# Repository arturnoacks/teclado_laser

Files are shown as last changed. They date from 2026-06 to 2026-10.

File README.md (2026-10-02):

# Teclado Laser Multi-Instrumental
- Projeto Integrado de Computação II - INF16193/ELE16194
- Artur Noack de Souza, Eduarda Tonini Ferri, Heitor Pinheiro Sousa e Luiz Gabriel Figueiredo Carvalho

O projeto consiste em um teclado multi-instrumental cujo acionamento das teclas ocorre ao interromper um feixe *laser*. De modo geral, o sistema de acionamento pode ser resumido em um conjunto de 24 circuitos emissor comum, que são chaveados de acordo com a resistência de cada LDR (inicialmente saturados pela luz dos *lasers*). Os sinais de saída são recebidos pelo Arduino Mega, que se comunica com o Arduino Uno e o VS1053 para gerar uma saída de áudio via porta P2. Parâmetros diversos como volume e instrumento podem ser visualizados e manipulados por meio de uma interface *web* gerenciada por um ESP32. Adicionalmente, um *encoder* rotativo também pode alterar esses parâmetros.

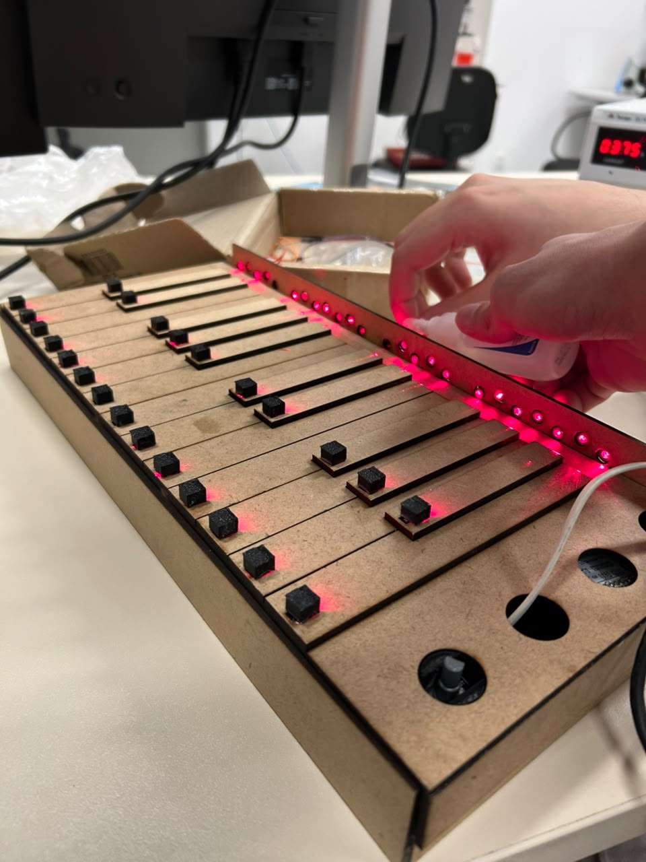
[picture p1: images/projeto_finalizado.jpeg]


Figura 1: Projeto finalizado do teclado laser.

## Descrição do código

O projeto é dividido em duas partes principais:

* **Hardware**: executado nos microcontroladores (Arduino Mega, Arduino Uno e ESP32), responsável pela leitura das teclas, geração do áudio MIDI e comunicação com a interface web.
* **Software**: aplicação responsável pela interface do usuário, permitindo controlar parâmetros do teclado e visualizar, em tempo real, as teclas pressionadas.

### Hardware

#### Arduino Mega

O Arduino Mega é o controlador principal do sistema.

Suas responsabilidades são:

* realizar a leitura das 24 teclas do teclado laser;
* detectar eventos de Note ON e Note OFF;
* converter cada sensor na respectiva nota MIDI;
* aplicar o deslocamento de oitava selecionado;
* enviar comandos MIDI para o Arduino Uno;
* controlar o encoder rotativo para alteração de volume, instrumento e oitava;
* comunicar-se com a ESP32 através da interface Serial2 utilizando mensagens JSON.

#### Arduino Uno + MIDI Shield

O Arduino Uno é responsável exclusivamente pela geração do áudio.

* inicializa o VS1053 em modo Real-Time MIDI;
* recebe os comandos MIDI enviados pelo Arduino Mega através da comunicação serial;
* encaminha esses comandos ao VS1053 via interface SPI;
* reproduz o áudio correspondente ao instrumento e nota selecionados.

#### ESP32

A ESP32 realiza a comunicação entre o hardware e a interface web. Ela conecta-se à rede Wi-Fi, hospeda um servidor WebSocket e faz a troca de mensagens entre o Arduino Mega e a aplicação web. Assim, alterações realizadas na interface são enviadas ao hardware, enquanto os eventos gerados pelo teclado e pelo encoder são transmitidos em tempo real para a interface.

#### Como executar

Carregue cada código na placa correspondente. Antes de fazer upload na ESP32, configure as credenciais da rede Wi-Fi:

```
const char* ssid = "SEU_WIFI";
const char* password = "SUA_SENHA";
```

Após a inicialização, a ESP32 exibirá no monitor serial o seu endereço IP.

### Software

#### Interface web

A interface web permite controlar os principais parâmetros do teclado, como volume, instrumento e oitava, além de exibir, em tempo real, as teclas pressionadas durante a execução. A comunicação com o hardware é realizada por meio de uma conexão WebSocket estabelecida com a ESP32, garantindo a sincronização entre a interface e o instrumento físico.

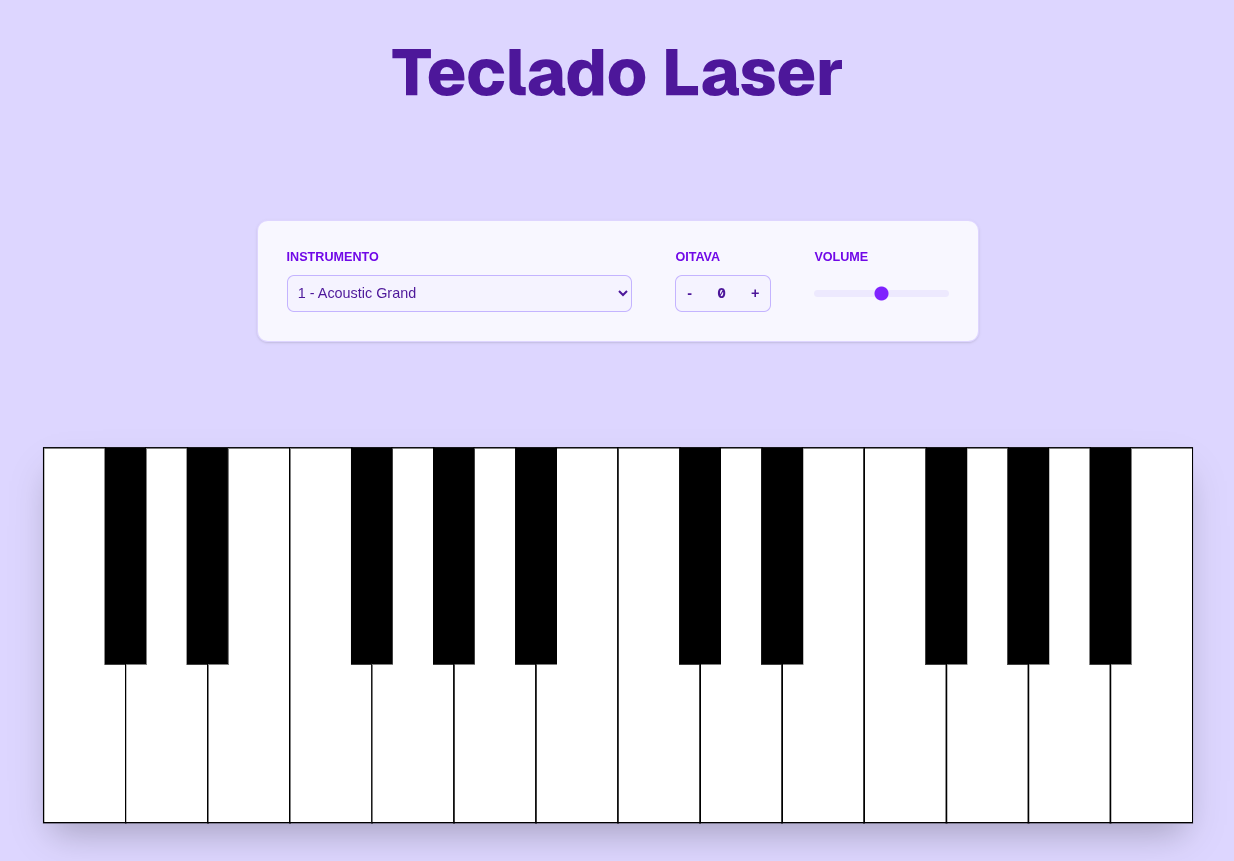
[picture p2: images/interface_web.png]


Figura 2: Tela da interface web.

#### Como executar

Configure o endereço IP da ESP32 utilizado pela conexão WebSocket em app/components/page.tsx:

```
const ESP_IP = "IP_DA_ESP"; 
```

No diretório da aplicação, instale as dependências:

```
npm install
```

Execute o servidor de desenvolvimento:

```
npm run dev
```

Abra http://localhost:3000 no seu navegador para acessar a interface.

## Descrição do material

### Lista de materiais:
- **Micro Controladores:**
	 - Arduino Mega 2560
	 - Arduino Uno
	 - ESP32
	 - Shield Arduino VS1053
 - **Componentes Eletrônicos:**
	 - 24 Módulos Diodo Laser 5V
	 - 24 Resistores 10k, 4.7k
	 - 24 Transistores BC547
	 - 24 LDR 5mm
	 - 1 Encoder Rotativo
 - **Impressões 3D:**
	 - Suportes para carcaça, *encoder* e *lasers*
	 - Proteção para LDRs
- **Outros Materiais:**
	- 4 Placas Fenolite Cobreada
	- 1 Placa Fenolite Perfurada
	- Fios e Jumpers Diversos
	- Carcaça de Madeira

## Modelos 3D (e MDF)
O primeiro modelo feito foi a caixa do piano, que, como seria feita em MDF, foi desenhada no *software* de CAD 2D QCAD. Após confecção desse modelo, ele foi enviado para uma loja de artigos em MDF que produziu grande parte da caixa corretamente, mas houveram algumas adaptações feitas pela loja para facilitar a produção da caixa. Isso fez com que algumas medidas do teclado ao final não sejam condizentes com o modelo do QCAD, mas ainda servem de referência.

O primeiro modelo 3D pensado foram as caixinhas dos LDRs: pequenas caixas pretas vazadas apenas para baixo e para frente, feitas para cobrirem cada LDR virado em direção aos *lasers*, prevenindo interferências de iluminação externa e ao mesmo tempo protegendo o ambiente ao redor do piano de poluição visual dos feixes que atravessassem o LDR. Ao total, foram utilizadas 24 caixinhas.

Conforme o desenvolvimento do projeto, foi percebido que o meio do piano, que é relativamente longo, ficaria curvo e frágil sem sustentação por baixo, ainda mais conforme as teclas fossem pressionadas. Para isso, foram impressos alguns suportes 3D, sendo colados à tampa e possuindo espaços vazados para a passagem de cabos e fios. Na mesma lógica, foi impresso um suporte para o *encoder*, uma vez que ele não poderia ser pressionado sem afundar na caixa caso ele não tivesse uma base firme.

Por fim, a última impressão feita foram os anéis de fixação dos *lasers* na parede posterior do teclado. Eles serviram para maior facilidade para colar os lasers, permitindo uma melhor calibragem do que seria possível caso eles fossem colados diretamente no buraco da parede.

Todos esses modelos constam na pasta "models" do repositório. A maioria dos arquivos estão em FCStd, que é o formato padrão do software FreeCAD utilizado para modelagem 3D das peças.

## Projetos de Placas

O processo de criação das placas foi feita a partir da criação de apenas uma nota, que foi replicada 24 vezes para a completude do piano. Cada uma das notas foi feita à partir de um circuito Emissor Comum, como o da imagem abaixo, de forma que o emissor do transistor fosse conectado direto ao terra, R1 = 4.7k Ohms, Rc = 10k Ohms e R2 fosse um LDR, que possui entre 50 e 100 Ohms quando saturado, ou seja, com o laser apontado. 

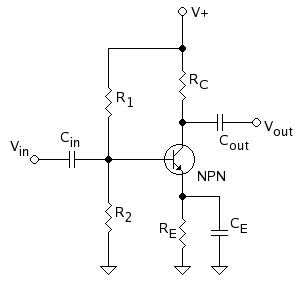
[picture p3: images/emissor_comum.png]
Exemplo de circuito Emissor Comum.


Figura 3: Exemplo de circuito Emissor Comum.

Dessa forma, quando o laser é impedido por um obstáculo, o transistor entra em corte e a saída cai. Quando o obstáculo é retirado, o LDR satura e o transistor volta a passar corrente, e a saída volta a 5V. Essa lógica é invertida em software.

Depois disso, foi utilizado o software KiCad, onde foram feitos 2 projetos, o primeiro sendo a junção de 5 notas e o segundo de 7 notas. 

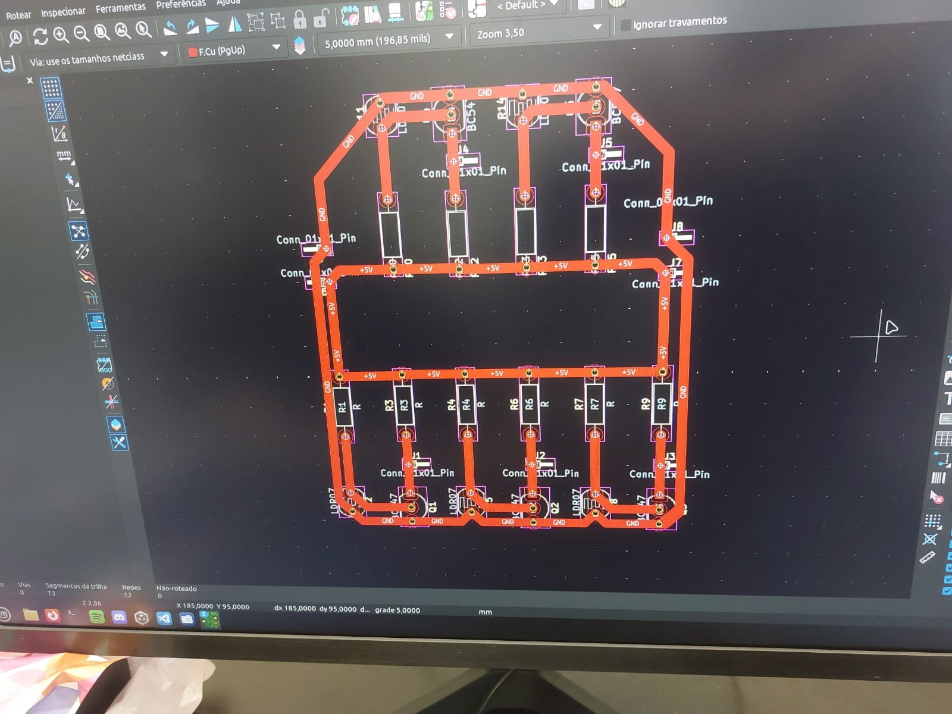
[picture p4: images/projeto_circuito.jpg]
Projeto do circuito de 5 notas no KiCad


Figura 4: Projeto do circuito de 5 notas no KiCad.

Isso foi feito por questão de espaço físico na máquina CnC, que foi utilizada para gravura do circuito na placa. Cada placa foi pintada com uma tinta preta que reage à luz ultra-violeta, de forma que a CnC pudesse disparar um laser forte e secar a tinta no formato do circuito desejado. Depois da gravura, a tinta que não havia sido seca foi retirada com álcool 70%, a placa foi cortada sob medida e por fim imersa em percloreto de ferro, para que o cobre fosse dissolvido.

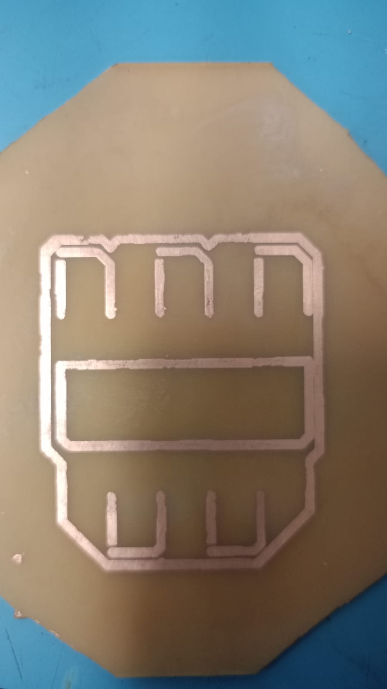
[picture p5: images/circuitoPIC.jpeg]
Placa de circuito impresso de 5 notas


Figura 5: Placa de circuito impresso de 5 notas.

Depois da produção da placa, ela foi limpa e raspada com o lado verde de uma esponja molhada com álcool, e furada manualmente. Então, foram soldados todos os componentes como no projeto desenvolvido. 

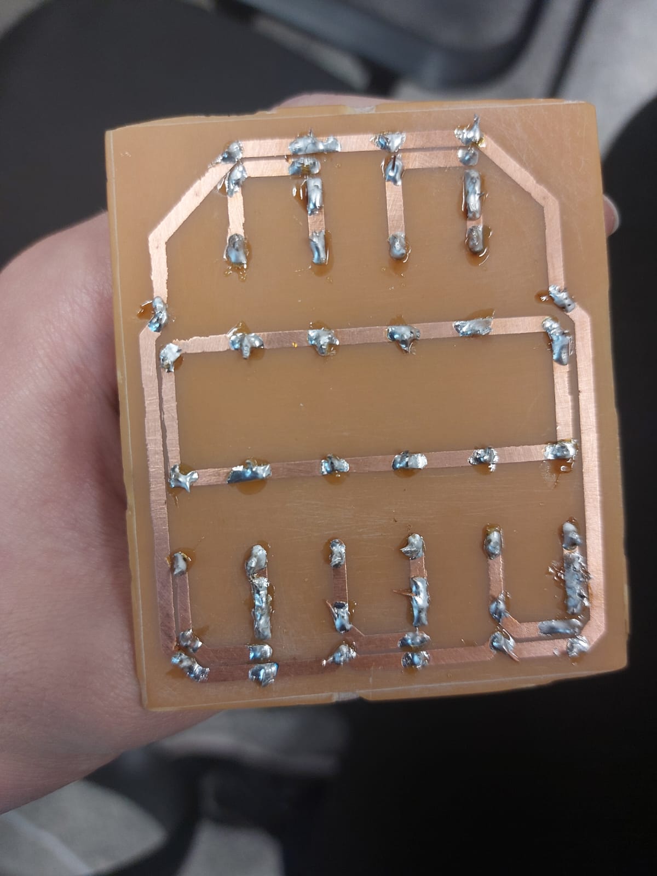
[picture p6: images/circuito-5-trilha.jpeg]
Circuito de 5 notas soldado


Figura 6: Placa de circuito impresso de 5 notas pronta.

As trilhas de 5V e GND foram soldadas com seus equivalentes em cada placa por meio de fios de cobre envernizados, e todos os fios de sinais das notas foram soldados em um barramento comum, que pudesse ser facilmente utilizado para se conectar por jumpers no Arduino Mega utilizado.

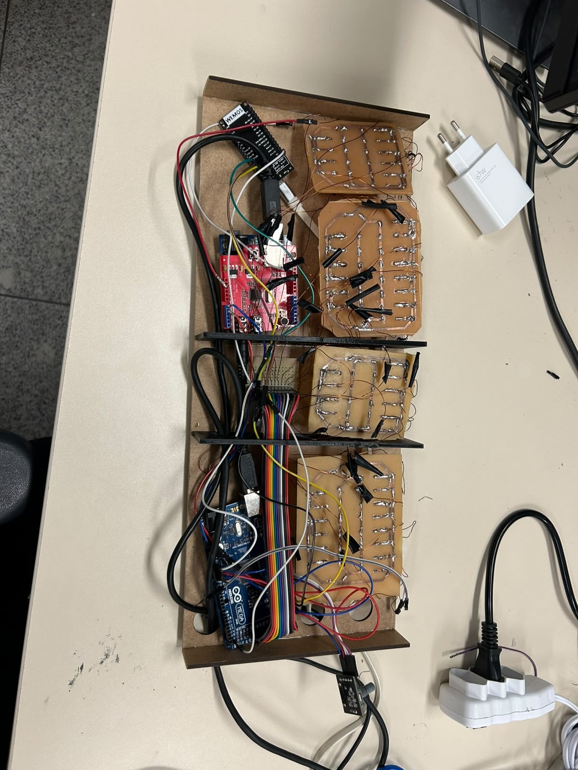
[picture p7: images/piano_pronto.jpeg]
Piano montado com todas as placas soldadas.


Figura 7: Piano montado com todas as placas soldadas.

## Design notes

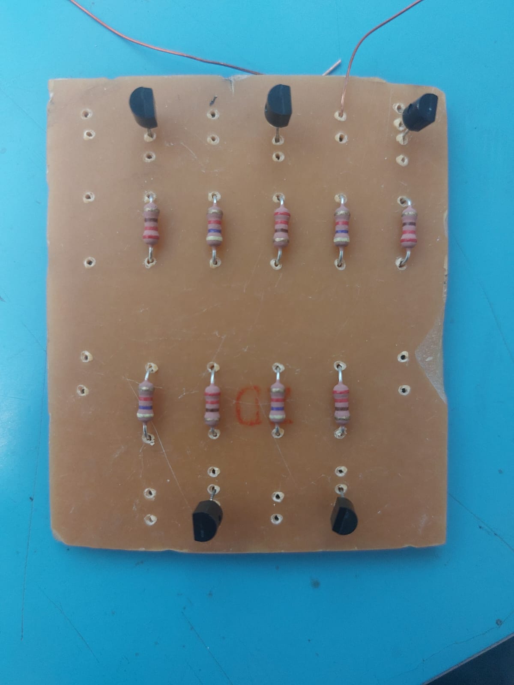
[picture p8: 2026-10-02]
images/circuito-5-frente.jpeg

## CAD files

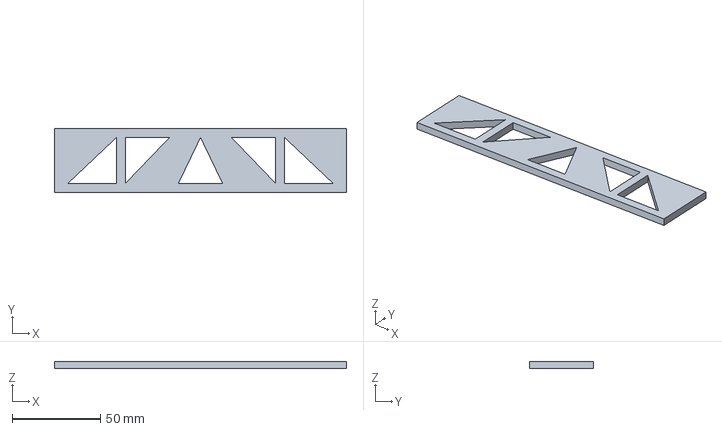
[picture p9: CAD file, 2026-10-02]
models/suportepianolaser.FCStd
165.0 x 36.0 x 4.00 mm

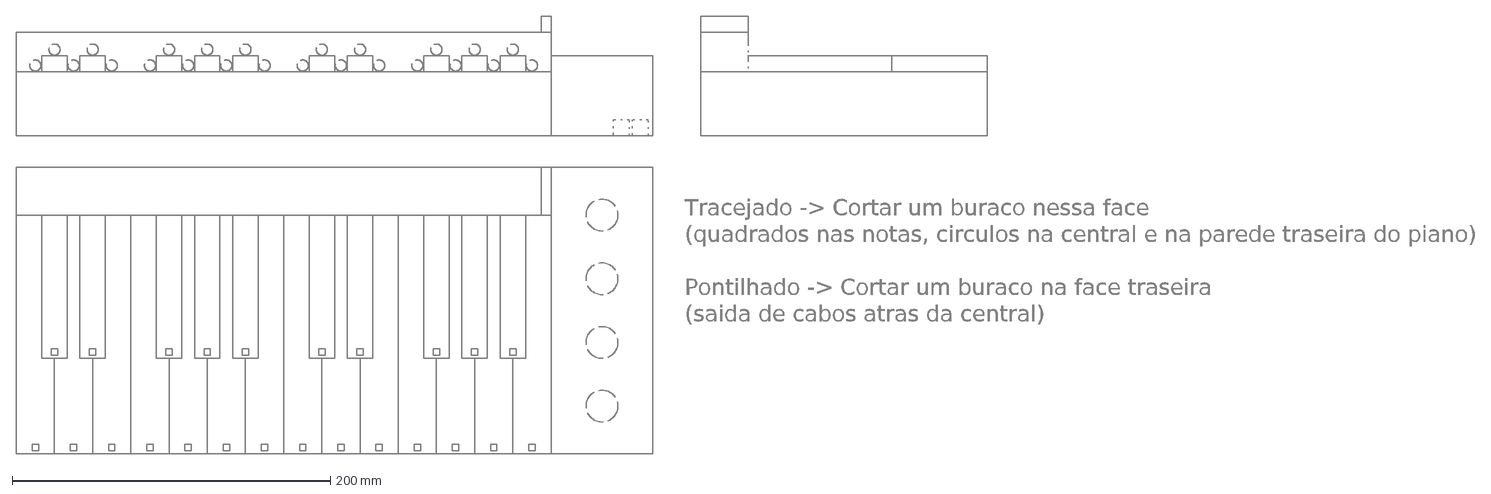
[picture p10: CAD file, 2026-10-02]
models/caixapianolaser.dxf
Tracejado -> Cortar um buraco nessa face (quadrados nas notas, circulos na central e na parede traseira do piano) Pontilhado -> Cortar um buraco na face traseir

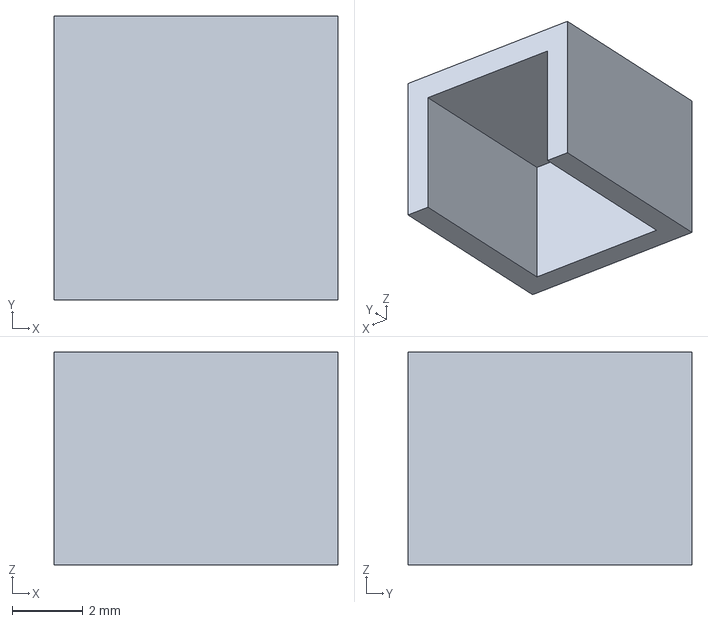
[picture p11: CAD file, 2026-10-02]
models/cabecinhapianolaser.FCStd
8.00 x 8.00 x 6.00 mm

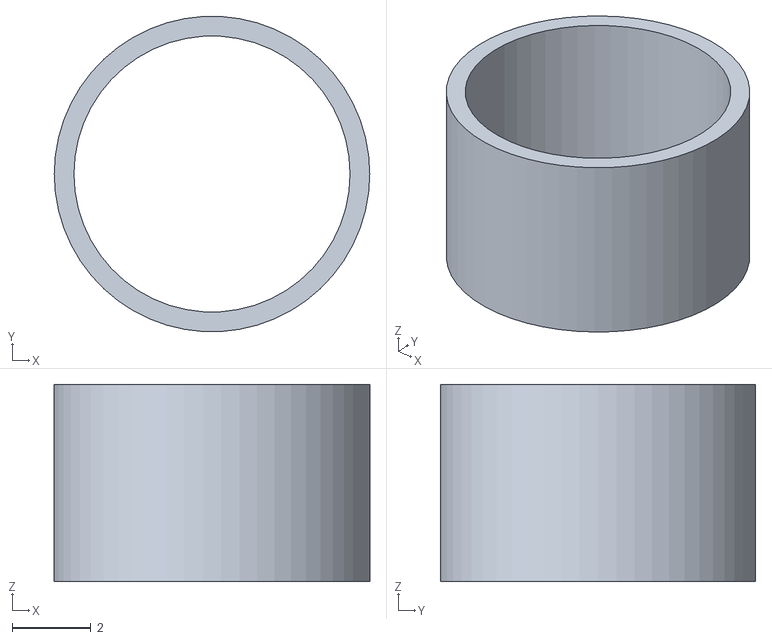
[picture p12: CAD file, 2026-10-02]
models/superluvalaser.stl
8.00 x 7.99 x 5.00

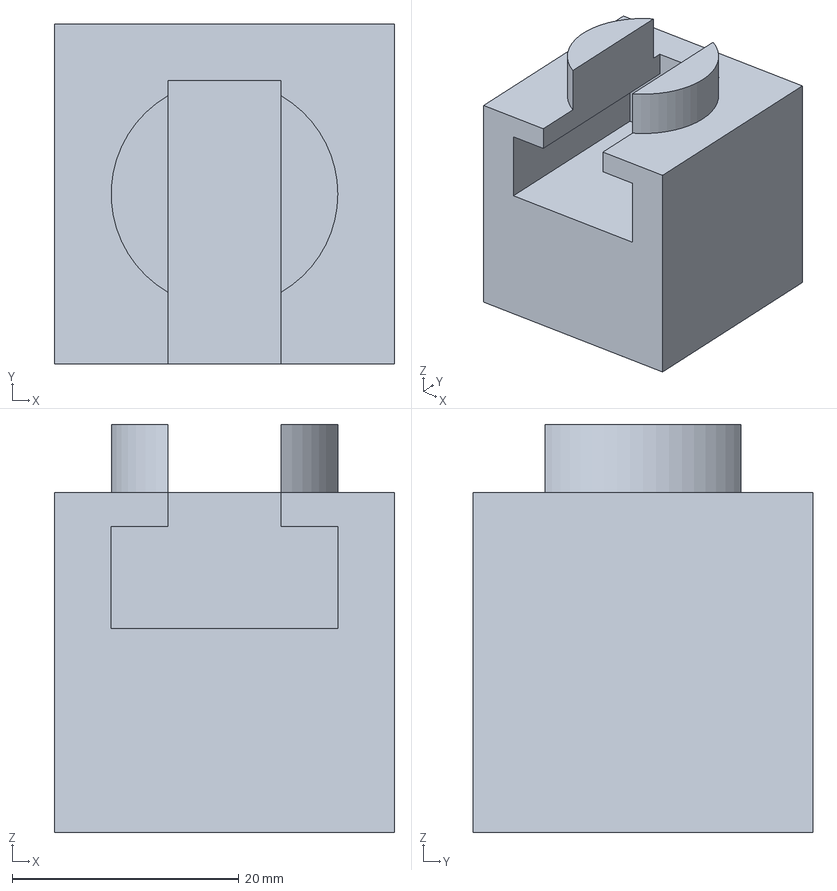
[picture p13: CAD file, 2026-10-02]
models/supencoder.FCStd
30.0 x 30.0 x 36.0 mm

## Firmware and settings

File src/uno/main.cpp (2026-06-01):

#include <Arduino.h>
#include <Wire.h>
#include <SoftwareSerial.h>
/*
// Simple DIY Electronic Music Projects
//    diyelectromusic.wordpress.com
//
//  Arduino MIDI VS1053 Synth
//  https://diyelectromusic.wordpress.com/2020/07/08/arduino-midi-vs1053-synth/
//
      MIT License
      
      Copyright (c) 2020 diyelectromusic (Kevin)
      
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
      THE SOFTWARE IS PROVIDED "AS IS", WITHOUT WARRANTY OF ANY KIND, EXPRESS OR
      IMPLIED, INCLUDING BUT NOT LIMITED TO THE WARRANTIES OF MERCHANTABILITY, FITNESS
      FOR A PARTICULAR PURPOSE AND NONINFRINGEMENT. IN NO EVENT SHALL THE AUTHORS OR
      COPYRIGHT HOLDERS BE LIABLE FOR ANY CLAIM, DAMAGES OR OTHER LIABILITY, WHETHERIN
      AN ACTION OF CONTRACT, TORT OR OTHERWISE, ARISING FROM, OUT OF OR IN CONNECTION
      WITH THE SOFTWARE OR THE USE OR OTHER DEALINGS IN THE SOFTWARE.
*/
/*
  Using principles from the following Arduino tutorials:
    Arduino MIDI Library - https://github.com/FortySevenEffects/arduino_midi_library
    Real-time MIDI Mode for the VS1053 - https://gist.github.com/microtherion/2636608
    Sparkfun Musical Instrument Shield Tutorial - https://www.sparkfun.com/tutorials/302
    VS1053 software patches - http://www.vlsi.fi/en/support/software/vs10xxpatches.html

  This uses a generic VS1053 MP3 Player board that does not
  support booting up into real time MIDI mode and does not
  support the RX/TX serial port MIDI connections.

  If you have a board that supports those, such as the
  SparkFun Musical Instrument Shield linked above, or
  the Adafruit VD1053 breakout board, then things are a
  lot simpler and you can use the basic libraries provided
  with those boards instead.

  This code uses the SPI MIDI mode and a software "patch"
  provided by the VS1053 maufacturers to put the chip into
  real-time MIDI mode.  This is the more complicated technique
  but is pretty much universal on all VS1053 based boards.

  Many thanks to Matthias Neeracher and Nathan Seidle for
  publishing the code that explains how all this works.

*/
#include <SPI.h>
#include <MIDI.h>

// Use binary to say which MIDI channels this should respond to.
// Every "1" here enables that channel. Set all bits for all channels.
// Make sure the bit for channel 10 is set if you want drums.
//
//                               16  12  8   4  1
//                               |   |   |   |  |
uint16_t MIDI_CHANNEL_FILTER = 0b1111111111111111;

// Channel to link to the potentiometer
#define POT_MIDI_CHANNEL 1

// VS1053 Shield pin definitions
#define VS_XCS    6 // Control Chip Select Pin (for accessing SPI Control/Status registers)
#define VS_XDCS   7 // Data Chip Select / BSYNC Pin
#define VS_DREQ   2 // Data Request Pin: Player asks for more data
#define VS_RESET  8 // Reset is active low

// There are three selectable sound banks on the VS1053
// These can be selected using the MIDI command 0xBn 0x00 bank
#define DEFAULT_SOUND_BANK 0x00  // General MIDI 1 sound bank
#define DRUM_SOUND_BANK    0x78  // Drums
#define ISNTR_SOUND_BANK   0x79  // General MIDI 2 sound bank

// List of instruments to send to any configured MIDI channels.
byte preset_instruments[16] = {
/* 01 */  0,
/* 02 */  0,
/* 03 */  0,
/* 04 */  0,
/* 05 */  0,
/* 06 */  0,
/* 07 */  0,
/* 08 */  0,
/* 09 */  0,
/* 10 */  0,  // Channel 10 will be ignored later as that is percussion anyway.
/* 11 */  0,
/* 12 */  0,
/* 13 */  0,
/* 14 */  0,
/* 15 */  0,
/* 16 */  0
};

// This is required to set up the MIDI library.
// The default MIDI setup uses the built-in serial port.
MIDI_CREATE_DEFAULT_INSTANCE();

byte instrument;

byte state = 0;
/***********************************************************************************************
 * 
 * Here is the code to send MIDI data to the VS1053 over the SPI bus.
 *
 * Taken from MP3_Shield_RealtimeMIDI.ino by Matthias Neeracher
 * which was based on Nathan Seidle's Sparkfun Electronics example code for the Sparkfun 
 * MP3 Player and Music Instrument shields and and VS1053 breakout board.
 *
 ***********************************************************************************************
 */
void sendMIDI(byte data) {
  SPI.transfer(0);
  SPI.transfer(data);
}

void talkMIDI(byte cmd, byte data1, byte data2) {
  //
  // Wait for chip to be ready (Unlikely to be an issue with real time MIDI)
  //
  while (!digitalRead(VS_DREQ)) {
  }
  digitalWrite(VS_XDCS, LOW);
  
  sendMIDI(cmd);
  
  //Some commands only have one data byte. All cmds less than 0xBn have 2 data bytes 
  //(sort of: http://253.ccarh.org/handout/midiprotocol/)
  if( (cmd & 0xF0) <= 0xB0 || (cmd & 0xF0) >= 0xE0) {
    sendMIDI(data1);
    sendMIDI(data2);
  } else {
    sendMIDI(data1);
  }

  digitalWrite(VS_XDCS, HIGH);
}


/***********************************************************************************************
 * 
 * Code from here on is the magic required to initialise the VS1053 and 
 * put it into real-time MIDI mode using an SPI-delivered patch.
 * 
 * Here be dragons...
 *
 * Taken from MP3_Shield_RealtimeMIDI.ino by Matthias Neeracher
 * which was based on Nathan Seidle's Sparkfun Electronics example code for the Sparkfun 
 * MP3 Player and Music Instrument shields and and VS1053 breakout board.
 *
 ***********************************************************************************************
 */

void VSLoadUserCode(void);

//Write to VS10xx register
void initialiseVS1053 () {
  // Set up the pins controller the SPI link to the VS1053
  pinMode(VS_DREQ, INPUT);
  pinMode(VS_XCS, OUTPUT);
  pinMode(VS_XDCS, OUTPUT);
  digitalWrite(VS_XCS, HIGH);  //Deselect Control
  digitalWrite(VS_XDCS, HIGH); //Deselect Data
  pinMode(VS_RESET, OUTPUT);

  //Setup SPI for VS1053
  pinMode(10, OUTPUT); // Pin 10 must be set as an output for the SPI communication to work
  SPI.begin();
  SPI.setBitOrder(MSBFIRST);
  SPI.setDataMode(SPI_MODE0);
  
  //From page 12 of datasheet, max SCI reads are CLKI/7. Input clock is 12.288MHz. 
  //Internal clock multiplier is 1.0x after power up. 
  //Therefore, max SPI speed is 1.75MHz. We will use 1MHz to be safe.
  SPI.setClockDivider(SPI_CLOCK_DIV16); //Set SPI bus speed to 1MHz (16MHz / 16 = 1MHz)
  SPI.transfer(0xFF); //Throw a dummy byte at the bus
  
  delayMicroseconds(1);
  digitalWrite(VS_RESET, HIGH); //Bring up VS1053
  
  // Enable real-time MIDI mode
  VSLoadUserCode();
}
//SCI: Data transfers are always 16bit. When a new SCI operation comes in 
//DREQ goes low. We then have to wait for DREQ to go high again.
//XCS should be low for the full duration of operation.
void VSWriteRegister(unsigned char addressbyte, unsigned char highbyte, unsigned char lowbyte){
  while(!digitalRead(VS_DREQ)) ; //Wait for DREQ to go high indicating IC is available
  digitalWrite(VS_XCS, LOW); //Select control
  
  //SCI consists of instruction byte, address byte, and 16-bit data word.
  SPI.transfer(0x02); //Write instruction
  SPI.transfer(addressbyte);
  SPI.transfer(highbyte);
  SPI.transfer(lowbyte);
  while(!digitalRead(VS_DREQ)) ; //Wait for DREQ to go high indicating command is complete
  digitalWrite(VS_XCS, HIGH); //Deselect Control
}

//
// Plugin to put VS10XX into realtime MIDI mode
// Originally from http://www.vlsi.fi/fileadmin/software/VS10XX/vs1053b-rtmidistart.zip
// Permission to reproduce here granted by VLSI solution.
//
const unsigned short sVS1053b_Realtime_MIDI_Plugin[28] = { /* Compressed plugin */
  0x0007, 0x0001, 0x8050, 0x0006, 0x0014, 0x0030, 0x0715, 0xb080, /*    0 */
  0x3400, 0x0007, 0x9255, 0x3d00, 0x0024, 0x0030, 0x0295, 0x6890, /*    8 */
  0x3400, 0x0030, 0x0495, 0x3d00, 0x0024, 0x2908, 0x4d40, 0x0030, /*   10 */
  0x0200, 0x000a, 0x0001, 0x0050,
};

void VSLoadUserCode(void) {
  int i = 0;

  while (i<sizeof(sVS1053b_Realtime_MIDI_Plugin)/sizeof(sVS1053b_Realtime_MIDI_Plugin[0])) {
    unsigned short addr, n, val;
    addr = sVS1053b_Realtime_MIDI_Plugin[i++];
    n = sVS1053b_Realtime_MIDI_Plugin[i++];
    while (n--) {
      val = sVS1053b_Realtime_MIDI_Plugin[i++];
      VSWriteRegister(addr, val >> 8, val & 0xFF);
    }
  }
}

SoftwareSerial SerialMEGA(A0, A1);

void setup() {
      
  // put your setup code here, to run once:
  initialiseVS1053();
  
  // This listens to all MIDI channels
  // They will be filtered out later...
  MIDI.begin(MIDI_CHANNEL_OMNI);

  SerialMEGA.begin(9600);

  Serial.begin(9600);
  pinMode(A2, INPUT);
  

  delay(1000);

  // A test "output" to see if the VS053 is working ok
#ifdef POT_MIDI_CHANNEL
  for (byte i=60; i<73; i++) {
    talkMIDI (0x90|(POT_MIDI_CHANNEL-1), i, 127);
    delay (100);
    talkMIDI (0x80|(POT_MIDI_CHANNEL-1), i, 0);
    delay (200);
  }
  for (byte i=40; i<50; i++) {
    talkMIDI (0x99, i, 127);
    delay (100);
    talkMIDI (0x89, i, 0);
    delay (200);    
  }
#endif

  // Configure the instruments for all required MIDI channels.
  // Even though MIDI channels are 1 to 16, all the code here
  // is working on 0 to 15 (bitshifts, index into array, MIDI command).
  for (byte ch=0; ch<16; ch++) {
    if (ch != 9) { // Ignore channel 10 (drums)
      uint16_t ch_filter = 1<<ch;
      if (MIDI_CHANNEL_FILTER & ch_filter) {
        talkMIDI(0xC0|ch, preset_instruments[ch], 0);
      }
    }
  }
  // For some reason, the last program change isn't registered
  // without an extra "dummy" read here.
  talkMIDI(0x80, 0, 0);
}

void loop() {

  byte midi[3];
    if(SerialMEGA.available() >= 3) {
      for(int i = 0; i < 3; i++) {
        midi[i] = SerialMEGA.read();
      }
      talkMIDI(midi[0], midi[1], midi[2]);
    }
  // put your main code here, to run repeatedly:

  // Read the potentiometer for a value between 0 and 127
  // to use to select the instrument in the general MIDI bank
  // for POT_MIDI_CHANNEL (if defined).
// #ifdef POT_MIDI_CHANNEL
//   byte pot = analogRead (A0) >> 3;
//   if (pot != instrument) {
//     // Change the instrument to play
//     instrument = pot;
//     talkMIDI(0xC0 | (POT_MIDI_CHANNEL-1), instrument, 0);
//   }
// #endif

  // If we have MIDI data then forward it on.
  // Based on the DualMerger.ino example from the MIDI library.
  //
//  if (MIDI.read()) {
    // Extract the channel and type to build the command to pass on
    // Recall MIDI channels are in the range 1 to 16, but will be
    // encoded as 0 to 15.
    //
    // All commands in the range 0x80 to 0xE0 support a channel.
    // Any command 0xF0 or above do not (they are system messages).
    // 

  // if(digitalRead(4)){
  //   for (byte i=40; i<50; i++) {
  //       talkMIDI (0x90, i, 127);
  //       delay (100);
  //       talkMIDI (0x80, i, 0);
  //       delay (200);    
  //     }
  // } 
/////////////////MIDI

    //Serial.println(digitalRead(A2));
    
    /* int stateAtual = 1 ? digitalRead(A2) == LOW : 0;
    if(state != stateAtual){
      state = 1 - state;
      if (state == 1) talkMIDI(0x90, 60, 127);
      else talkMIDI(0x80, 60, 127);
    } */

    // byte ch = MIDI.getChannel();
    // uint16_t ch_filter = 1<<(ch-1);  // bit numbers are 0 to 15; channels are 1 to 16
    // if (ch == 0) ch_filter = 0xffff; // special case - always pass system messages where ch==0
    // if (MIDI_CHANNEL_FILTER & ch_filter) {
    //   byte cmd = MIDI.getType();
    //   if ((cmd >= 0x80) && (cmd <= 0xE0)) {
    //     // Merge in the channel number
    //     cmd |= (ch-1);
    //   }
    //   talkMIDI(cmd, MIDI.getData1(), MIDI.getData2());
    // }
//  }
}

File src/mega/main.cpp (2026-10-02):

#include <Arduino.h>
#include "encoder.hpp"

#define NUM_NOTES 24
#define FIRST_PIN_NOTES 22
#define LAST_PIN_NOTES 45
#define ON 0
#define OFF 1

//////////////// notes
byte pin_to_note_array[24] = {60, 58, 62, 56, 64, 54, 61, 59, 63, 57, 65, 55, 67, 53, 69, 51, 71, 49, 66, 50, 68, 52, 70, 48};
byte note_status[24];
byte pin_to_note(uint8_t pin){
    return constrain(int(pin_to_note_array[pin-22] + (get_octave() * 12)), 0, 127);
}

void setup(){
    Serial.begin(9600);
    Serial1.begin(9600);
    Serial2.begin(115200);
    
    for(int i=0; i<NUM_NOTES; i++){
        note_status[i] = digitalRead(FIRST_PIN_NOTES + i);
    }
    
    encoder_setup();
}


void loop(){
    
    handle_encoder_press();

    receive_from_esp();
    
    for(int i=0; i<NUM_NOTES; i++){
        uint8_t pin = FIRST_PIN_NOTES + i;
        byte note = pin_to_note(pin);

        int stateAtual = digitalRead(pin);
        if(stateAtual != note_status[i]){
            note_status[i] = 1 - note_status[i];

            String jsonNota = "{\"n\":";
            jsonNota += (note%24) + 48;
            jsonNota += ",\"s\":";
            
            if(note_status[i] == ON){
                noteON(note);
                jsonNota += "1}";
                Serial.print("Note ");Serial.print(note);Serial.println(" ON");
            }
            else{
                noteOFF(note);
                jsonNota += "0}";
                Serial.print("Note ");Serial.print(note);Serial.println(" OFF");
            }

            Serial2.println(jsonNota);
        }
    }
    
    delay(10); // Small stability delay
}

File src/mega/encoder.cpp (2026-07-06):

#include "encoder.hpp"
#include <ArduinoJson.h>

//////////////////// instrument and octave
int lastClkState;
unsigned long last_encoder_press = 0;
unsigned long last_encoder_rotation = 0;
encoderMode modo = INSTRUMENTO;

byte volume = 63;
byte instrumento = 0;
int oitava = 0; //-3 a 4

void encoder_setup(){    
    // Setup Encoder Pins with Internal Pull-ups
    pinMode(ENCODER_CLK, INPUT_PULLUP);
    pinMode(ENCODER_DT, INPUT_PULLUP);
    pinMode(ENCODER_SW, INPUT_PULLUP); // Enable pull-up for the switch

    lastClkState = digitalRead(ENCODER_CLK);
    attachInterrupt(digitalPinToInterrupt(ENCODER_CLK), read_encoder, CHANGE);
}

void handle_encoder_press(){
    int btnState = digitalRead(ENCODER_SW);
  
    if (btnState == LOW && (millis() - last_encoder_press > 200)) {
        modo = (encoderMode)((modo+1)%ENCODER_MODES);

        last_encoder_press = millis();
        
        Serial.print("Ja muda, agora é ");
        Serial.println(modo);
    }
}

void send_to_esp(){
    String json = "{\"v\":";
    json += volume;
    json += ",\"i\":";
    json += instrumento;
    json += ",\"o\":";
    json += oitava;
    json += "}";
    
    Serial2.println(json);
    Serial.println("Enviado: " + json);
}

void receive_from_esp() {
    if (Serial2.available()) {
        String input = Serial2.readStringUntil('\n');

        StaticJsonDocument<200> doc; 
        
        DeserializationError error = deserializeJson(doc, input);

        if (!error) {
            if (doc.containsKey("v")) {
                volume = doc["v"];
                setVolume(volume);
            }
            if (doc.containsKey("i")) {
                instrumento = doc["i"];
                setInstrument(instrumento);
            }
            if (doc.containsKey("o")) {
                oitava = doc["o"];
            }
        } else {
            Serial.print("Erro ao ler JSON da ESP: ");
            Serial.println(error.c_str());
        }
    }
}

void read_encoder(){
    
    if(millis() - last_encoder_rotation > 50){ // debouncer
       last_encoder_rotation = millis();

        int clkState = digitalRead(ENCODER_CLK);
    
        if (clkState != lastClkState) {
            lastClkState = clkState;
            bool clockwise = (digitalRead(ENCODER_DT) != clkState); //sentido

            bool alterado = false;
            
            switch (modo)
            {
                case VOLUME:
                    if(clockwise) volume = constrain((int)volume+16,0,127);
                    else volume = constrain((int)volume-16,0,127);
                    setVolume(volume);
                    alterado = true;
                    Serial.print("Volume "); Serial.println(volume);
                    break;
                case INSTRUMENTO:
                    if(clockwise) instrumento = constrain((int)instrumento+1,0,127);
                    else instrumento = constrain((int)instrumento-1,0,127);
                    setInstrument(instrumento);
                    alterado = true;
                    Serial.print("instrumento "); Serial.println(instrumento);
                    break;
                case OITAVA:
                    if(clockwise) oitava++;
                    else oitava--;
                    oitava = constrain(oitava, -3, 4);
                    alterado = true;
                    Serial.print("oitava "); Serial.println(oitava);
                    break;
                // case VOLUME:
                // /* code */
                // break;
                default:
                    break;
            }

            if (alterado) {
                send_to_esp();
            }
        }
    }
}

int get_octave(){
    return oitava;
}

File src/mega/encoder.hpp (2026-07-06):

#ifndef ENCODER_H
#define ENCODER_H

#include <Arduino.h>
#include "midi.hpp"
#define ENCODER_CLK 2
#define ENCODER_DT 3
#define ENCODER_SW 4

#define ENCODER_MODES 3
typedef enum{
    VOLUME, INSTRUMENTO, OITAVA
}encoderMode;

void encoder_setup();

void handle_encoder_press();

void send_to_esp();

void receive_from_esp();

void read_encoder();

int get_octave();
#endif

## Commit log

2026-05-14 envio de notas
2026-06-01 sabor limpeza de codigo
2026-07-14 modelos adicionados
    [cabecinhapianolaser.FCStd, caixapianolaser.dxf, supencoder.FCStd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]
2026-07-15 descrição do código no README
    Expanded project description with detailed hardware and software sections, including setup instructions for the Arduino Mega, Arduino Uno, and ESP32, as well as the web interface.
2026-07-15 adicionadas imagens do circuito
2026-07-16 correções nas imagens e nos resistores
2026-10-06 versao ct portas abertas de verdade
